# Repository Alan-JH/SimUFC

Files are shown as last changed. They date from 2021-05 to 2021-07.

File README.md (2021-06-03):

# SimUFC
UFC design for DCS, based on the F-18C Hornet

Display panels originally designed by [OpenHornet](https://github.com/jrsteensen/OpenHornet) and remixed to use .1" headers and multiplexed digits instead of multiplexed half digits.

Displays driven by Holtek HT1632Cs. Board is designed to take Cherry style key switches. I am using Kailh Box Jades, hence the SMD LEDs.

Main assembly is two large PCBs stacked, with the back PCB housing the LED drivers and microcontroller. It is designed to also take a shift register PCB of one of my older designs. It will be replaced later on.

Microcontroller is an STM32 Bluepill.

[][cc-by-nc-sa]

This work is licensed under a
[Creative Commons Attribution-NonCommercial-ShareAlike 4.0 International License][cc-by-nc-sa].

[][cc-by-nc-sa]

[cc-by-nc-sa]: http://creativecommons.org/licenses/by-nc-sa/4.0/
[cc-by-nc-sa-image]: https://licensebuttons.net/l/by-nc-sa/4.0/88x31.png
[cc-by-nc-sa-shield]: https://img.shields.io/badge/License-CC%20BY--NC--SA%204.0-lightgrey.svg

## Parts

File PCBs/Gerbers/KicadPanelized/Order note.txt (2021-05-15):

Please see Eco1_User and Cmts_User layers for internal cut instructions. The panel should include three modules, separated by mouse bite tabs.

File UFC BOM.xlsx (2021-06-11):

Category | Part | Qty | Price (Estimate) | Notes | Link
Switch | Kailh Box Jade keyswitch | 24 | $40 for 65 | clicc clacc | https://www.amazon.com/gp/product/B0841HQFCL/
Microcontroller | STM32F103C8T6 Bluepill | 1 | $14, with ST-Link programmer | cheaper on aliexpress etc. | https://www.ebay.com/itm/292286013429
LED Multiplexer | HT1632C-52LQFP | 2 | $6 for 5, from china | QFP52 part, buy from ebay/aliexpress. Adafruit uses HT16K33 for their 14 segs, seems to only be able to drive 8 at once. | https://www.ebay.com/itm/181847042276
 |  |  |  | HT1632C is EOL according to Holtek, but HT1632D, its replacement, is non stocked everywhere.
Resistor | 560R 1/4W 1206 | 34 | $14 for two assortments | 1206 SMD, Used for the multiplexer outputs to LEDs, should limit current to around 2mA | Assortment on amazon (buy two): https://www.amazon.com/gp/product/B08RYMYWG9
 | 300R 1/4W 1206 | 2 |  | 1206 SMD, Used for LED backlighting
 | 100R 1/4W 1206 | 22 |  | 1206 SMD, Used for LED backlighting (two LEDs in series, parallel with everything else. See schematic)
Diode | 1N4148 Diode | 17 | $5 for 125 |  | https://www.amazon.com/gp/product/B07Q4F3Y5W/
LED | Kingbright APT2012MGC | 24 | $11 | 0805 LED, used for backlighting keypads. Any ~2V, 20-30mA LED should work with this design. Recommend something decently bright | https://www.mouser.com/ProductDetail/kingbright/apt2012mgc/
Capacitor | 0603 .1uF X7R cap | 1 | $7 for a 100 pc reel | Decoupling capacitors | https://www.ebay.com/itm/202703146857
Displays | Modified Openhornet displays (OPT + Scratchpad + COM) | * | ~$40 for 5 panels | order from JLCPCB with SMT assembly | See gerber files on repo
 | ^Includes 177 0402 LEDs to be assembled
PCBs | Main PCB | 1 | ~$10 for 5 | order from JLCPCB, no SMT assembly. Solder yourself, or pay extra for SMT
 | Back side PCB | 1 | ~$10 for 5 | order from JLCPCB, no SMT assembly. Solder yourself, or pay extra for SMT
 | Lower Bar PCB | 1 | ~$6 for 5 | order from JLCPCB, no SMT assembly. Solder yourself, or pay extra for SMT
MOSFET | IPP120P04P4L03AKSA2 | 1 | $3 | Or other P channel mosfet of your choosing; requires low-ish RDSon, Id > 240mA at Vgs -5V, and Vgs threshold above 1.5V, give or take. | https://www.mouser.com/ProductDetail/726-IPP120P04P4L03A2
 |  |  |  | OR just redesign for analog control of backlight, with potentiometer of your choosing.
Connectors | Ribbon cable with Dupont connectors | 4 | ~$10, probably | Can be crimped yourself, but takes hours. Need two each of 8 wire, and 9 wire. Used for connecting comm displays
 | Female and male pin headers | * | $10 | Need lots of them. 40 pin, 30 pcs assortment is plenty. | https://www.amazon.com/gp/product/B074HVBTZ4/

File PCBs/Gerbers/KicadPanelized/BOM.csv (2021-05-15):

Comment | Designator | Footprint | LCSC Part Number
Green LED, 20mA | D1-177 | 0402 | C130722

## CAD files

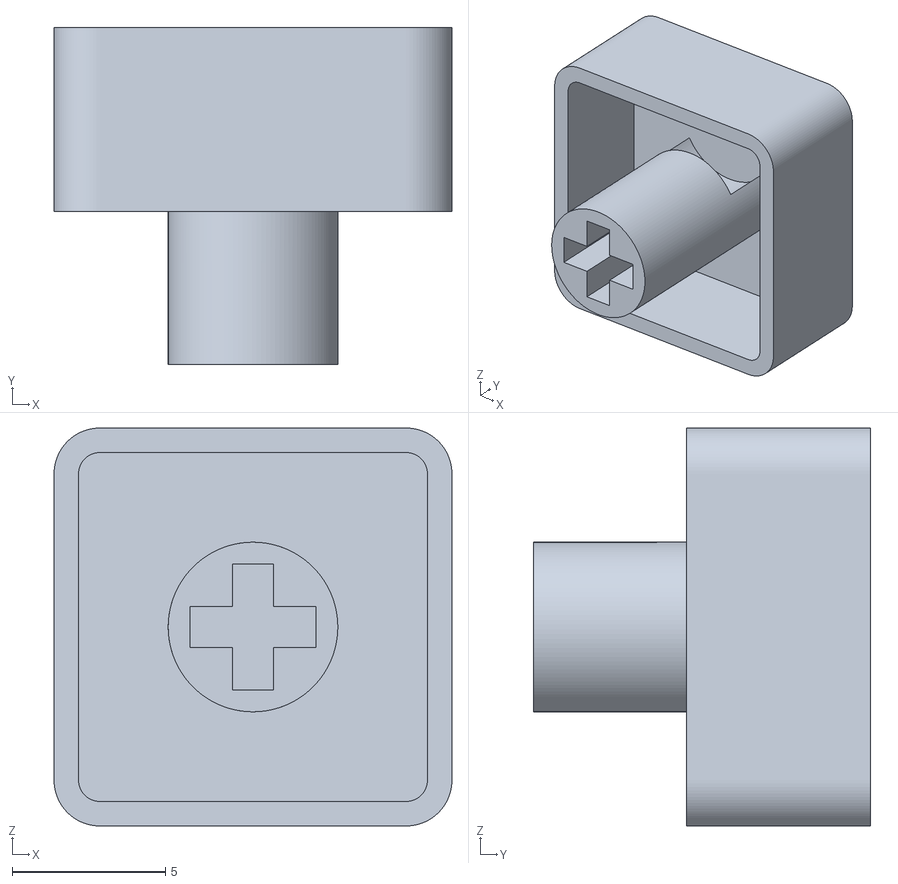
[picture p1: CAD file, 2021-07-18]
MCAD/STL Export/KeyENT.stl
13.0 x 11.0 x 13.0

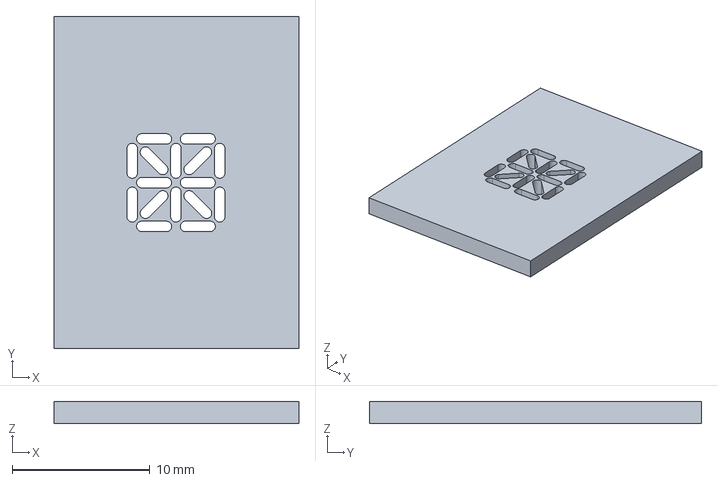
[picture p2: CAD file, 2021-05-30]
PCBs/Display layers updated/ufc_v4_comm_layer3.step
17.8 x 24.1 x 1.60 mm

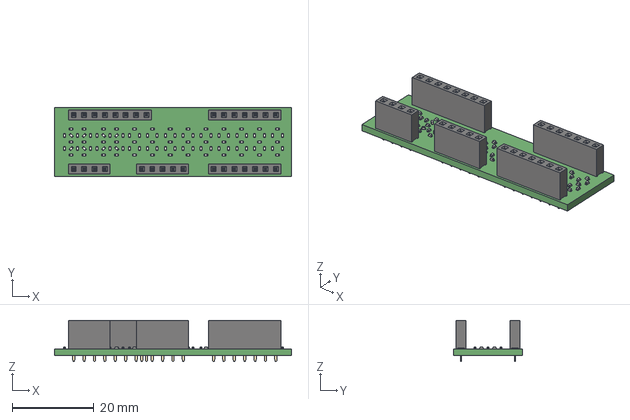
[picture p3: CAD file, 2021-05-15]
PCBs/ufc_v4_scratchpad.step
57.9 x 16.8 x 10.1 mm

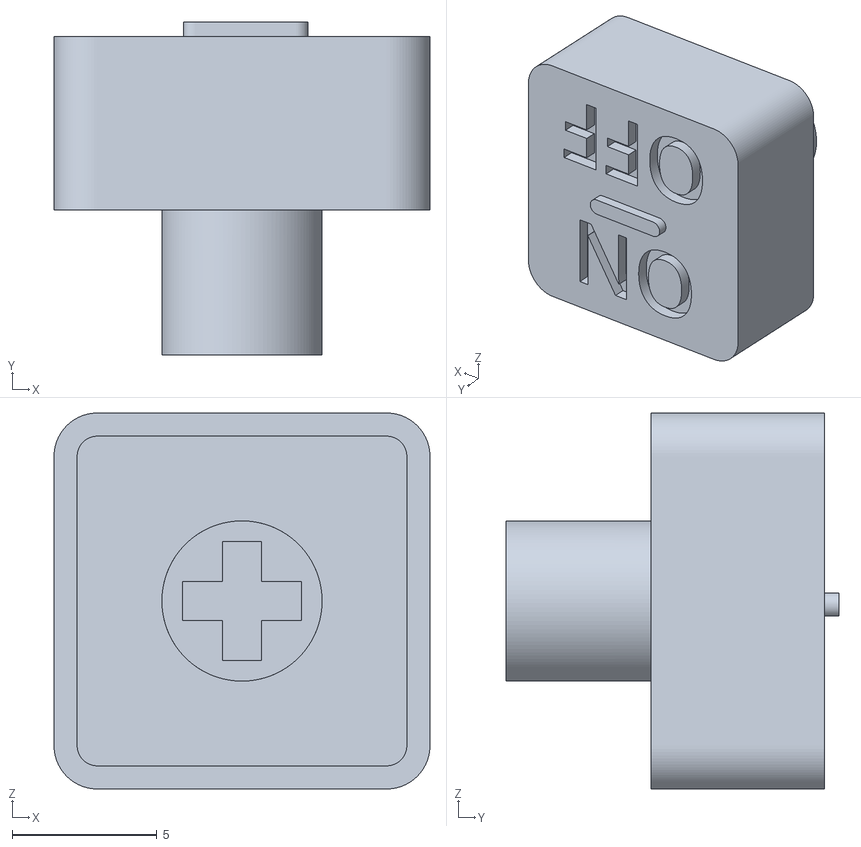
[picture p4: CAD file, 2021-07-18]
MCAD/STL Export/KeyONOFF.stl
13.0 x 11.5 x 13.0

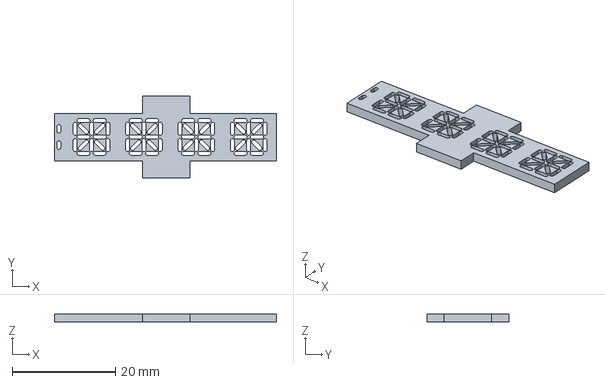
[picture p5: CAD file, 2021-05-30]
PCBs/Display layers updated/ufc_v4_opt_layer3.step
43.1 x 15.9 x 1.60 mm

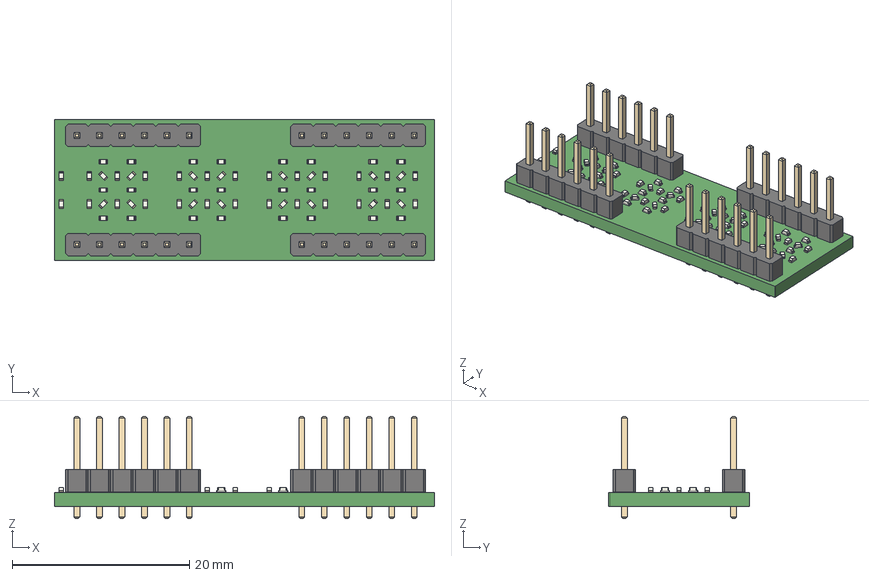
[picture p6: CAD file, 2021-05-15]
PCBs/ufc_v4_opt.step
42.9 x 15.9 x 11.5 mm

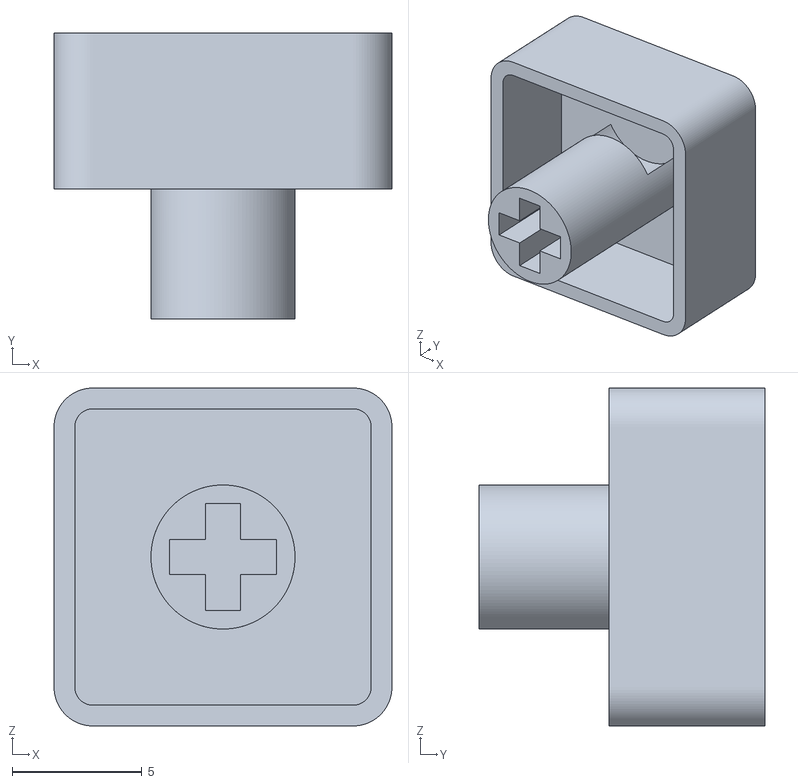
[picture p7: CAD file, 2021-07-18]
MCAD/STL Export/Key7.stl
13.0 x 11.0 x 13.0

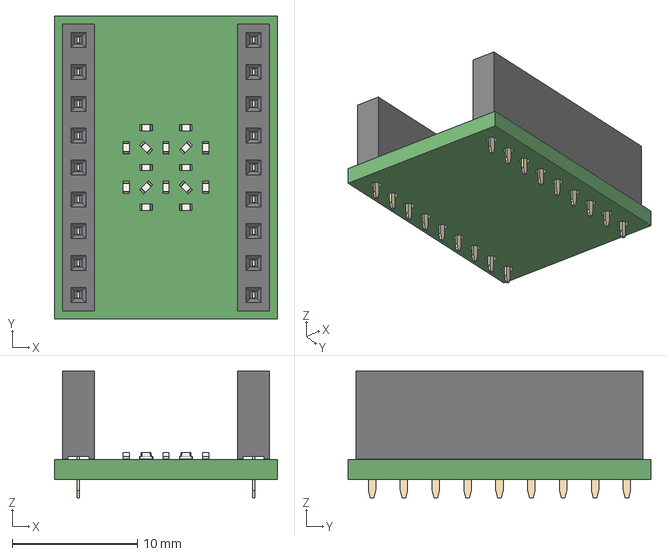
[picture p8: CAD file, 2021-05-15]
PCBs/ufc_v4_comm.step
17.8 x 24.1 x 10.1 mm

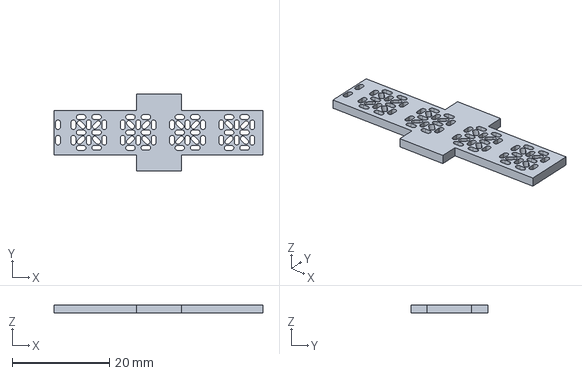
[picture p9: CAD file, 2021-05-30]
PCBs/Display layers updated/ufc_v4_opt_layer2.step
43.1 x 15.9 x 1.60 mm

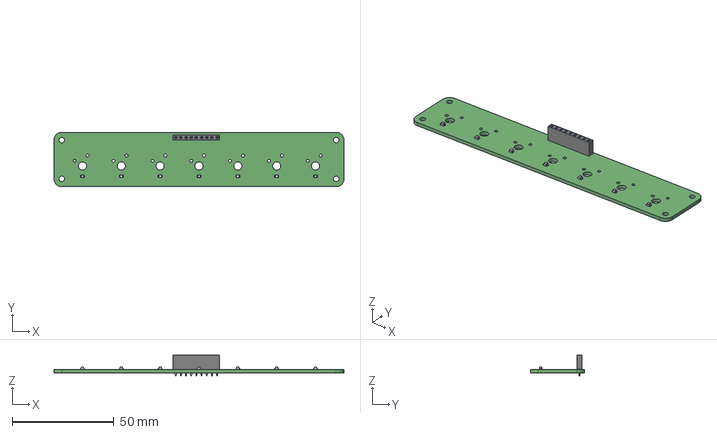
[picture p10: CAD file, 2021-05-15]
PCBs/LowerBar.step
142.2 x 26.7 x 10.1 mm

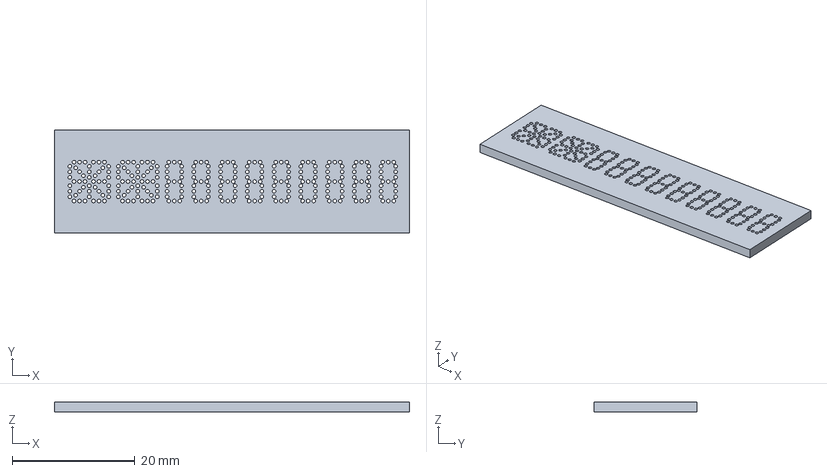
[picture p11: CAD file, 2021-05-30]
PCBs/Display layers updated/ufc_v4_scratchpad_layer4.step
58.0 x 16.8 x 1.60 mm

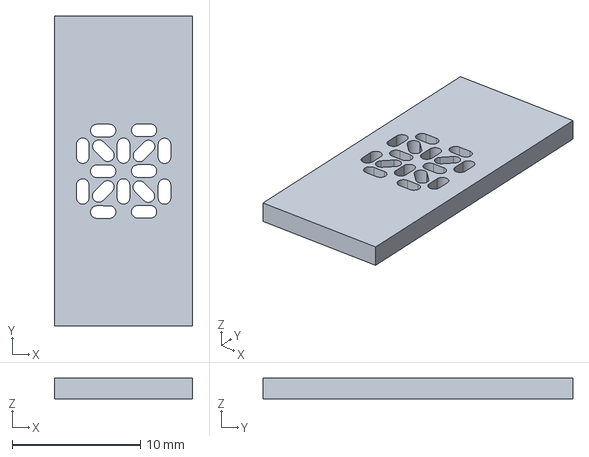
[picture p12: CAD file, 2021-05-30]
PCBs/Display layers updated/ufc_v4_comm_layer2.step
10.8 x 24.1 x 1.60 mm

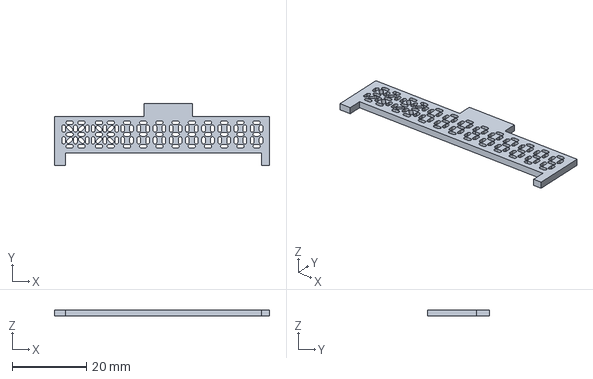
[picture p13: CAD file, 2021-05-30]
PCBs/Display layers updated/ufc_v4_scratchpad_layer2.step
58.0 x 16.8 x 1.60 mm

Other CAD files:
PCBs/Display layers updated/ufc_v4_comm_layer4.step
MCAD/STL Export/KeyIFF.stl
MCAD/STL Export/Key1.stl
MCAD/STL Export/Key6.stl
MCAD/STL Export/Key4.stl
MCAD/STL Export/Back.stl
MCAD/STL Export/COMM retainer.stl
MCAD/STL Export/COMM.stl
MCAD/STL Export/Face spacer.stl
MCAD/STL Export/Face.stl
MCAD/STL Export/Key0.stl
MCAD/STL Export/Key2.stl
MCAD/STL Export/Key3.stl
MCAD/STL Export/Key5.stl
MCAD/STL Export/Key8.stl
MCAD/STL Export/Key9.stl
MCAD/STL Export/KeyAP.stl
MCAD/STL Export/KeyBCN.stl
MCAD/STL Export/KeyCLR.stl
MCAD/STL Export/KeyDL.stl
MCAD/STL Export/KeyILS.stl
MCAD/STL Export/KeyRound.stl
MCAD/STL Export/KeyTCN.stl
MCAD/STL Export/Keypadplate.stl
MCAD/STL Export/L side.stl
MCAD/STL Export/Lower bar spacer.stl
MCAD/STL Export/Lower bar switch plate.stl
MCAD/STL Export/OPT retainer.stl
MCAD/STL Export/PCB spacer.stl
MCAD/STL Export/R side.stl
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

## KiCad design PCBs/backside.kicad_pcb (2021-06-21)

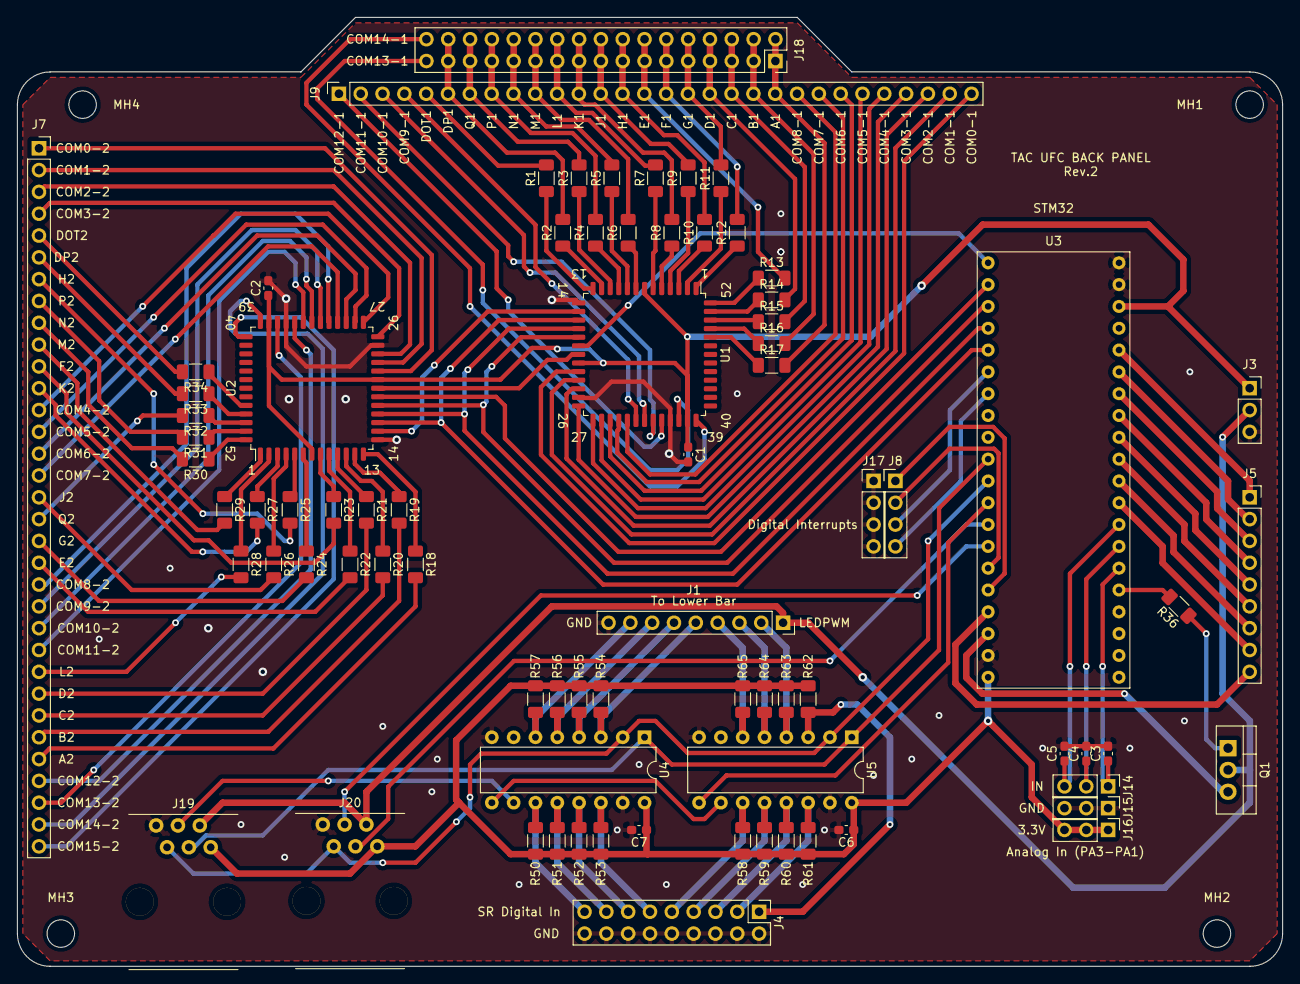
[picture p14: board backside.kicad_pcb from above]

Board: 2 copper layers, 147.3 x 110.5 mm, 82 parts (0 on the bottom side), 151 nets.

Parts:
C1, C2, C3, C4, C5, C6, C7: .1uF; C_0603_1608Metric_Pad1.08x0.95mm_HandSolder
J1: 9Pin; PinSocket_1x09_P2.54mm_Vertical
J3: Power; PinSocket_1x03_P2.54mm_Vertical
J4: Conn_02x09_Odd_Even; PinHeader_2x09_P2.54mm_Vertical
J5: Matrix; PinSocket_1x09_P2.54mm_Vertical
J7: Driver output 2; PinSocket_1x33_P2.54mm_Vertical
J8, J17: Conn_01x04_Male; PinHeader_1x04_P2.54mm_Vertical
J9: Conn_01x30_Male; PinSocket_1x30_P2.54mm_Vertical
J14, J15, J16: Conn_01x03_Male; PinHeader_1x03_P2.54mm_Vertical
J18: Conn_02x17_Odd_Even; PinSocket_2x17_P2.54mm_Vertical
J19, J20: RJ12; SS-6466-NF
MH1, MH2, MH3, MH4: MountingHole_3.2mm_M3
Q1: IPP120P04P4L03; TO-220-3_Vertical
R1, R2, R3, R4, R5, R6, R7, R8, R9, R10, R11, R12, R13, R14, R15, R16, R17, R18, R19, R20, R21, R22, R23, R24, R25, R26, R27, R28, R29, R30, R31, R32, R33, R34: 510R; R_1206_3216Metric_Pad1.30x1.75mm_HandSolder
R36: 100R; R_1206_3216Metric_Pad1.30x1.75mm_HandSolder
R50, R51, R52, R53, R54, R55, R56, R57, R58, R59, R60, R61, R62, R63, R64, R65: 10K; R_1206_3216Metric_Pad1.30x1.75mm_HandSolder
U1, U2: HT1632C-52LQFP; LQFP-52_14x14mm_P1mm
U3: STM32F103C8T6; Bluepill
U4, U5: 74HC165; DIP-16_W7.62mm

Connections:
/3.3V: C1.1, C2.1, C6.1, C7.1, J3.1, J16.1, J16.2, J16.3, J19.6, J20.6, R50.2, R51.2, R52.2, R53.2, R54.2, R55.2, R56.2, R57.2, R58.2, R59.2, R60.2, R61.2, R62.2, R63.2, R64.2, R65.2, U1.7, U1.21, U1.38, U2.7, U2.21, U2.38, U3.47, U3.52, U4.16, U5.16
/5V: Q1.3, U3.50
/A1: J9.21, J18.1, J18.2, R17.2
/A2: J7.29, R18.2
/Analog1: C3.1, J14.1, U3.11
/Analog2: C4.1, J14.2, U3.12
/Analog3: C5.1, J14.3, U3.13
/B1: J9.20, J18.3, J18.4, R16.2
/B2: J7.28, R19.2
/C1: J9.19, J18.5, J18.6, R15.2
/C2: J7.27, R20.2
/COL1: J5.4, U3.18
/COL2: J5.3, U3.19
/COL3: J5.2, U3.21
/COL4: J5.1, U3.22
/COM0-1: J9.30, U1.22
/COM0-2: J7.1, U2.22
/COM1-1: J9.29, U1.23
/COM1-2: J7.2, U2.23
/COM2-1: J9.28, U1.24
/COM2-2: J7.3, U2.24
/COM3-1: J9.27, U1.26
/COM3-2: J7.4, U2.26
/COM4-1: J9.26, U1.27
/COM4-2: J7.13, U2.27
/COM5-1: J9.25, U1.28
/COM5-2: J7.14, U2.28
/COM6-1: J9.24, U1.29
/COM6-2: J7.15, U2.29
/COM7-1: J9.23, U1.30
/COM7-2: J7.16, U2.30
/COM8-1: J9.22, U1.31
/COM8-2: J7.21, U2.31
/COM9-1: J9.4, U1.32
/COM9-2: J7.22, U2.32
/COM10-1: J9.3, U1.33
/COM10-2: J7.23, U2.33
/COM11-1: J9.2, U1.34
/COM11-2: J7.24, U2.34
/COM12-1: J9.1, U1.35
/COM12-2: J7.30, U2.35
/COM13-1: J18.33, U1.37
/COM13-2: J7.31, U2.37
/COM14-1: J18.34, U1.39
/COM14-2: J7.32, U2.39
/COM15-2: J7.33, U2.40
/CS1: U1.19, U3.25
/CS2: U2.19, U3.26
/D1: J9.18, J18.7, J18.8, R14.2
/D2: J7.26, R21.2
/DATA: U1.16, U2.16, U3.29
/DIN1: J4.1, R62.1, U5.3
/DIN2: J4.3, R61.1, U5.14
/DIN3: J4.5, R60.1, U5.13
/DIN4: J4.7, R59.1, U5.12
/DIN5: J4.9, R58.1, U5.11
/DIN6: J4.11, R53.1, U4.14
/DIN7: J4.13, R52.1, U4.13
/DIN8: J4.15, R51.1, U4.12
/DIN9: J4.17, R50.1, U4.11
/DOT1: J9.5, R1.2
/DOT2: J7.5, R34.2
/DP1: J9.6, J18.31, J18.32, R2.2
/DP2: J7.6, R33.2
/DSIN: J19.3, U4.10
/DigInt1: J8.1, U3.45
/DigInt2: J8.2, U3.43
/DigInt3: J8.3, U3.30
/DigInt4: J8.4, U3.31
/E1: J9.15, J18.13, J18.14, R13.2
/E2: J7.20, R22.2
/F1: J9.16, J18.11, J18.12, R12.2
/F2: J7.11, R23.2
/G1: J9.17, J18.9, J18.10, R11.2
/G2: J7.19, R24.2
/GND: C1.2, C2.2, C3.2, C4.2, C5.2, C6.2, C7.2, J1.9, J3.3, J4.2, J4.4, J4.6, J4.8, J4.10, J4.12, J4.14, J4.16, J4.18, J15.1, J15.2, J15.3, J17.1, J17.2, J17.3, J17.4, J19.1, J20.1, U1.14, U1.25, U1.36, U2.14, U2.25, U2.36, U3.48, U3.49, U3.51, U4.8, U4.15, U5.8, U5.15
/H1: J9.14, J18.15, J18.16, R10.2
/H2: J7.7, R25.2
/J1: J9.13, J18.17, J18.18, R9.2
/J2: J7.17, R26.2
/K1: J9.12, J18.19, J18.20, R8.2
/K2: J7.12, R27.2
/L1: J9.11, J18.21, J18.22, R7.2
/L2: J7.25, R28.2
/LEDPWM: J1.1, J3.2, J19.5, J20.5, Q1.2
/M1: J9.10, J18.23, J18.24, R6.2
/M2: J7.10, R29.2
/N1: J9.9, J18.25, J18.26, R5.2
/N2: J7.9, R30.2
/OSC: U1.15, U2.15
/P1: J9.8, J18.27, J18.28, R4.2
/P2: J7.8, R31.2
/Q1: J9.7, J18.29, J18.30, R3.2
/Q2: J7.18, R32.2
/RD: U1.18, U2.18, U3.27
/ROW0: J5.5, U3.17
/ROW1: J5.6, U3.16
/ROW2: J5.7, U3.15
/ROW3: J5.8, U3.14
/ROW4: J5.9, U3.46
/SRCLK: J19.2, J20.2, U3.39, U4.2, U5.2
/SRCS: J19.4, U3.38, U4.1, U5.1
/SRCS2: J20.4, U3.41
/SRMISO: U3.40, U5.9
/SRMISO2: J20.3, U3.42
/SW18: J1.8, R57.1, U4.6
/SW19: J1.7, R56.1, U4.5
/SW20: J1.6, R55.1, U4.4
/SW21: J1.5, R54.1, U4.3
/SW22: J1.4, R65.1, U5.6
/SW23: J1.3, R64.1, U5.5
/SW24: J1.2, R63.1, U5.4
/SYNC: U1.20, U2.20
/WR: U1.17, U2.17, U3.28
unnamed: Q1.1, R36.1
unnamed: R1.1, U1.13
unnamed: R2.1, U1.12
unnamed: R3.1, U1.11
unnamed: R4.1, U1.10
unnamed: R5.1, U1.9
unnamed: R6.1, U1.8
unnamed: R7.1, U1.6
unnamed: R8.1, U1.5
unnamed: R9.1, U1.4
unnamed: R10.1, U1.3
unnamed: R11.1, U1.2
unnamed: R12.1, U1.1
unnamed: R13.1, U1.52
unnamed: R14.1, U1.51
unnamed: R15.1, U1.50
unnamed: R16.1, U1.49
unnamed: R17.1, U1.48
unnamed: R18.1, U2.13
unnamed: R19.1, U2.12
unnamed: R20.1, U2.11
unnamed: R21.1, U2.10
unnamed: R22.1, U2.9
unnamed: R23.1, U2.8
unnamed: R24.1, U2.6
unnamed: R25.1, U2.5
unnamed: R26.1, U2.4
unnamed: R27.1, U2.3
unnamed: R28.1, U2.2
unnamed: R29.1, U2.1
unnamed: R30.1, U2.52
unnamed: R31.1, U2.51
unnamed: R32.1, U2.50
unnamed: R33.1, U2.49
unnamed: R34.1, U2.48
unnamed: R36.2, U3.10
unnamed: U4.9, U5.10

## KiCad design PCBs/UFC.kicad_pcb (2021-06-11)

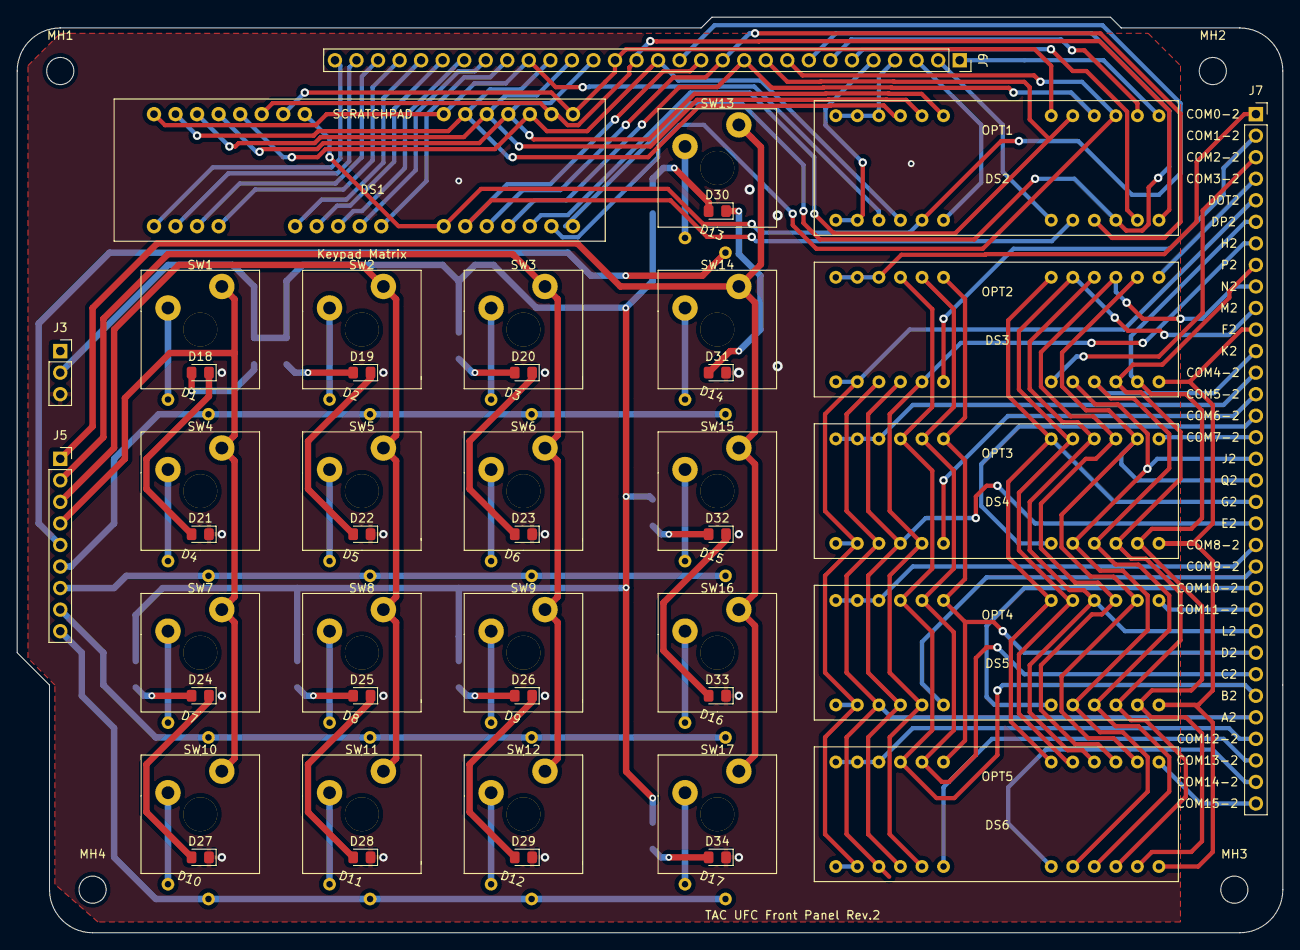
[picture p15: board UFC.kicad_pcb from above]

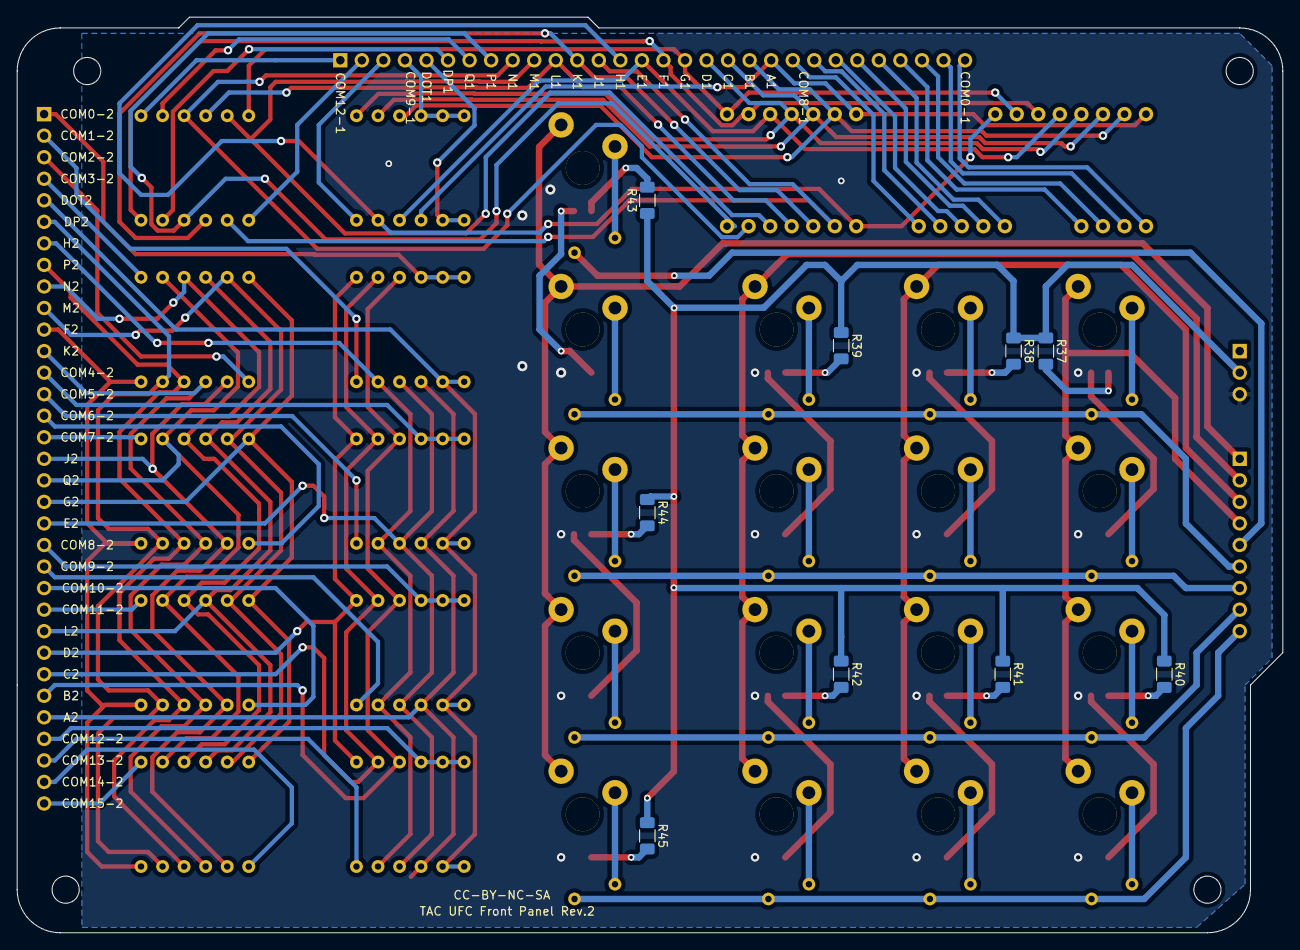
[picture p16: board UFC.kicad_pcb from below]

Board: 2 copper layers, 149.2 x 108.0 mm, 74 parts (9 on the bottom side), 108 nets.

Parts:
D1, D2, D3, D4, D5, D6, D7, D8, D9, D10, D11, D12, D13, D14, D15, D16, D17: D; 1N4148
D18, D19, D20, D21, D22, D23, D24, D25, D26, D27, D28, D29, D30, D31, D32, D33, D34: LED; LED_0805_2012Metric_Pad1.15x1.40mm_HandSolder
DS1: Scratchpad
DS2, DS3, DS4, DS5, DS6: CustomOptPanel; OPTDisplay
J3: Power; PinSocket_1x03_P2.54mm_Vertical
J5: Matrix; PinSocket_1x09_P2.54mm_Vertical
J7: Driver output 2; PinSocket_1x33_P2.54mm_Vertical
J9: Conn_01x30_Male; PinSocket_1x30_P2.54mm_Vertical
MH1, MH2, MH3, MH4: MountingHole_3.2mm_M3
R37, R38, R39, R40, R41, R42, R43, R44: 100R; R_1206_3216Metric_Pad1.30x1.75mm_HandSolder
R45: 300R; R_1206_3216Metric_Pad1.30x1.75mm_HandSolder
SW1, SW2, SW3, SW4, SW5, SW6, SW7, SW8, SW9, SW10, SW11, SW12, SW13, SW14, SW15, SW16, SW17: KeySW; KailhSW

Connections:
/A1: DS1.1, DS1.9, DS2.15, J9.21
/A2: DS3.15, DS4.15, DS5.15, DS6.15, J7.29
/B1: DS1.2, DS1.10, DS2.4, J9.20
/B2: DS3.4, DS4.4, DS5.4, DS6.4, J7.28
/C1: DS1.3, DS1.11, DS2.5, J9.19
/C2: DS3.5, DS4.5, DS5.5, DS6.5, J7.27
/COL1: J5.4, SW1.2, SW4.2, SW7.2, SW10.2
/COL2: J5.3, SW2.2, SW5.2, SW8.2, SW11.2
/COL3: J5.2, SW3.2, SW6.2, SW9.2, SW12.2
/COL4: J5.1, SW13.2, SW14.2, SW15.2, SW16.2, SW17.2
/COM0-1: DS1.16, J9.30
/COM0-2: DS3.1, DS3.2, DS3.3, J7.1
/COM1-1: DS1.17, J9.29
/COM1-2: DS3.18, J7.2
/COM2-1: DS1.18, J9.28
/COM2-2: DS3.19, J7.3
/COM3-1: DS1.19, J9.27
/COM3-2: DS3.12, J7.4
/COM4-1: DS1.20, J9.26
/COM4-2: DS4.1, DS4.2, DS4.3, J7.13
/COM5-1: DS1.21, J9.25
/COM5-2: DS4.18, J7.14
/COM6-1: DS1.22, J9.24
/COM6-2: DS4.19, J7.15
/COM7-1: DS1.23, J9.23
/COM7-2: DS4.12, J7.16
/COM8-1: DS1.24, J9.22
/COM8-2: DS5.1, DS5.2, DS5.3, J7.21
/COM9-1: DS2.1, DS2.2, DS2.3, J9.4
/COM9-2: DS5.18, J7.22
/COM10-1: DS2.18, J9.3
/COM10-2: DS5.19, J7.23
/COM11-1: DS2.19, J9.2
/COM11-2: DS5.12, J7.24
/COM12-1: DS2.12, J9.1
/COM12-2: DS6.1, DS6.2, DS6.3, J7.30
/COM13-2: DS6.18, J7.31
/COM14-2: DS6.19, J7.32
/COM15-2: DS6.12, J7.33
/D1: DS1.4, DS1.12, DS2.6, J9.18
/D2: DS3.6, DS4.6, DS5.6, DS6.6, J7.26
/DOT1: DS2.13, DS2.14, J9.5
/DOT2: DS3.13, DS3.14, DS4.13, DS4.14, DS5.13, DS5.14, DS6.13, DS6.14, J7.5
/DP1: DS2.23, J9.6
/DP2: DS3.23, DS4.23, DS5.23, DS6.23, J7.6
/E1: DS1.5, DS1.13, DS2.16, J9.15
/E2: DS3.16, DS4.16, DS5.16, DS6.16, J7.20
/F1: DS1.6, DS1.14, DS2.24, J9.16
/F2: DS3.24, DS4.24, DS5.24, DS6.24, J7.11
/G1: DS1.7, DS1.15, DS2.7, J9.17
/G2: DS3.7, DS4.7, DS5.7, DS6.7, J7.19
/GND: D21.1, D22.1, D23.1, D27.1, D28.1, D29.1, D31.1, D33.1, D34.1, J3.3
/H1: DS1.8, DS1.25, DS2.17, J9.14
/H2: DS3.17, DS4.17, DS5.17, DS6.17, J7.7
/J1: DS1.26, DS2.20, J9.13
/J2: DS3.20, DS4.20, DS5.20, DS6.20, J7.17
/K1: DS1.27, DS2.21, J9.12
/K2: DS3.21, DS4.21, DS5.21, DS6.21, J7.12
/L1: DS1.28, DS2.9, J9.11
/L2: DS3.9, DS4.9, DS5.9, DS6.9, J7.25
/LEDPWM: J3.2, R37.1, R38.1, R39.1, R40.1, R41.1, R42.1, R43.1, R44.1, R45.1
/M1: DS1.29, DS2.8, J9.10
/M2: DS3.8, DS4.8, DS5.8, DS6.8, J7.10
/N1: DS1.30, DS2.10, J9.9
/N2: DS3.10, DS4.10, DS5.10, DS6.10, J7.9
/P1: DS1.31, DS2.22, J9.8
/P2: DS3.22, DS4.22, DS5.22, DS6.22, J7.8
/Q1: DS2.11, J9.7
/Q2: DS3.11, DS4.11, DS5.11, DS6.11, J7.18
/ROW0: D13.1, J5.5
/ROW1: D1.1, D2.1, D3.1, D14.1, J5.6
/ROW2: D4.1, D5.1, D6.1, D15.1, J5.7
/ROW3: D7.1, D8.1, D9.1, D16.1, J5.8
/ROW4: D10.1, D11.1, D12.1, D17.1, J5.9
unnamed: D1.2, SW1.1
unnamed: D2.2, SW2.1
unnamed: D3.2, SW3.1
unnamed: D4.2, SW4.1
unnamed: D5.2, SW5.1
unnamed: D6.2, SW6.1
unnamed: D7.2, SW7.1
unnamed: D8.2, SW8.1
unnamed: D9.2, SW9.1
unnamed: D10.2, SW10.1
unnamed: D11.2, SW11.1
unnamed: D12.2, SW12.1
unnamed: D13.2, SW13.1
unnamed: D14.2, SW14.1
unnamed: D15.2, SW15.1
unnamed: D16.2, SW16.1
unnamed: D17.2, SW17.1
unnamed: D18.1, D21.2
unnamed: D18.2, R37.2
unnamed: D19.1, D22.2
unnamed: D19.2, R38.2
unnamed: D20.1, D23.2
unnamed: D20.2, R39.2
unnamed: D24.1, D27.2
unnamed: D24.2, R40.2
unnamed: D25.1, D28.2
unnamed: D25.2, R41.2
unnamed: D26.1, D29.2
unnamed: D26.2, R42.2
unnamed: D30.1, D31.2
unnamed: D30.2, R43.2
unnamed: D32.1, D33.2
unnamed: D32.2, R44.2
unnamed: D34.2, R45.2

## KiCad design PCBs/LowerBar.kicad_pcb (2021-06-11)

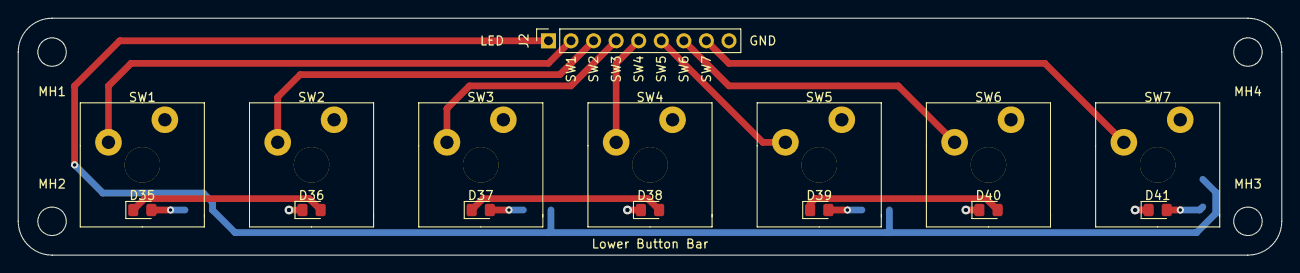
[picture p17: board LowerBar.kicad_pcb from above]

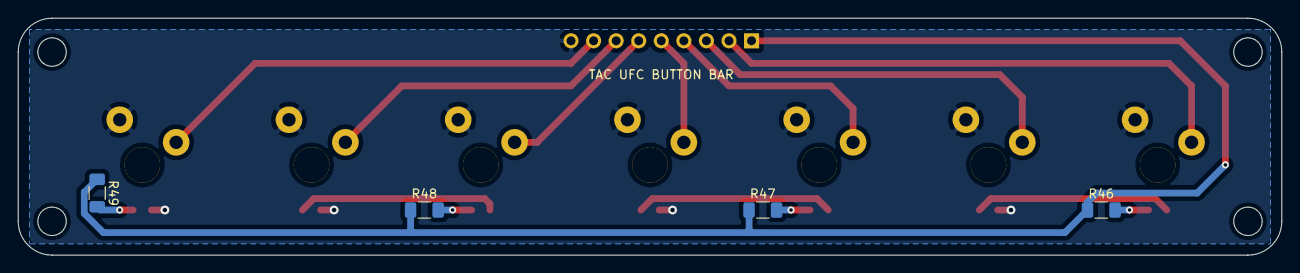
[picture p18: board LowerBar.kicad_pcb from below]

Board: 2 copper layers, 142.2 x 26.7 mm, 23 parts (4 on the bottom side), 16 nets.

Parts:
D35, D36, D37, D38, D39, D40, D41: LED; LED_0805_2012Metric_Pad1.15x1.40mm_HandSolder
J2: 9pin; PinSocket_1x09_P2.54mm_Vertical
MH1, MH2, MH3, MH4: M3; MountingHole_3.2mm_M3
R46, R47, R48: 100R; R_1206_3216Metric_Pad1.30x1.75mm_HandSolder
R49: 300R; R_1206_3216Metric_Pad1.30x1.75mm_HandSolder
SW1, SW2, SW3, SW4, SW5, SW6, SW7: KeySW; KailhSW

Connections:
/GND: D36.1, D38.1, D40.1, D41.1, J2.9, SW1.2, SW2.2, SW3.2, SW4.2, SW5.2, SW6.2, SW7.2
/LED: J2.1, R46.1, R47.1, R48.1, R49.1
/SW18: J2.2, SW1.1
/SW19: J2.3, SW2.1
/SW20: J2.4, SW3.1
/SW21: J2.5, SW4.1
/SW22: J2.6, SW5.1
/SW23: J2.7, SW6.1
/SW24: J2.8, SW7.1
unnamed: D35.1, D36.2
unnamed: D35.2, R46.2
unnamed: D37.1, D38.2
unnamed: D37.2, R47.2
unnamed: D39.1, D40.2
unnamed: D39.2, R48.2
unnamed: D41.2, R49.2

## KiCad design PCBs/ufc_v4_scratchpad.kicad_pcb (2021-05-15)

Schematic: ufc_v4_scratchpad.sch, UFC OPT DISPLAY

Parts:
D1, D2, D3, D4, D5, D6, D7, D8, D9, D10, D11, D12, D13, D14, D15, D16, D17, D18, D19, D20, D21, D22, D23, D24, D25, D26, D27, D28, D29, D30, D31, D32, D33, D34, D35, D36, D37, D38, D39, D40, D41, D42, D43, D44, D45, D46, D47, D48, D49, D50, D51, D52, D53, D54, D55, D56, D57, D58, D59, D60, D61, D62, D63, D64, D65, D66, D67, D68, D69, D70, D71, D72, D73, D74, D75, D76, D77, D78, D79, D80, D81, D82, D83, D84, D85, D86, D87, D88, D89, D90, D91, D92, D93, D94, D95: LED; LED_0402_1005Metric; LCSC C130723
J1: Conn_01x08_Male; PinHeader_1x08_P2.54mm_Vertical
J2: Conn_01x04_Male; PinHeader_1x04_P2.54mm_Vertical
J3, J5: Conn_01x07_Male; PinHeader_1x07_P2.54mm_Vertical
J6: Conn_01x05_Male; PinHeader_1x05_P2.54mm_Vertical

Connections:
/DIG0: D1.1 (K), D2.1 (K), D3.1 (K), D4.1 (K), D5.1 (K), D6.1 (K), D7.1 (K), D8.1 (K), J2.1
/DIG0_2: D33.1 (K), D34.1 (K), D35.1 (K), D36.1 (K), D37.1 (K), D38.1 (K), D39.1 (K), D61.1 (K), D62.1 (K), D63.1 (K), D64.1 (K), D65.1 (K), D66.1 (K), D67.1 (K), J6.1
/DIG1: D9.1 (K), D10.1 (K), D11.1 (K), D12.1 (K), D13.1 (K), D14.1 (K), D15.1 (K), D16.1 (K), J2.2
/DIG1_2: D40.1 (K), D41.1 (K), D42.1 (K), D43.1 (K), D44.1 (K), D45.1 (K), D46.1 (K), D68.1 (K), D69.1 (K), D70.1 (K), D71.1 (K), D72.1 (K), D73.1 (K), D74.1 (K), J6.2
/DIG2: D17.1 (K), D18.1 (K), D19.1 (K), D20.1 (K), D21.1 (K), D22.1 (K), D23.1 (K), D24.1 (K), J2.3
/DIG2_2: D47.1 (K), D48.1 (K), D49.1 (K), D50.1 (K), D51.1 (K), D52.1 (K), D53.1 (K), D75.1 (K), D76.1 (K), D77.1 (K), D78.1 (K), D79.1 (K), D80.1 (K), D81.1 (K), J6.3
/DIG3: D25.1 (K), D26.1 (K), D27.1 (K), D28.1 (K), D29.1 (K), D30.1 (K), D31.1 (K), D32.1 (K), J2.4
/DIG3_2: D54.1 (K), D55.1 (K), D56.1 (K), D57.1 (K), D58.1 (K), D59.1 (K), D60.1 (K), D82.1 (K), D83.1 (K), D84.1 (K), D85.1 (K), D86.1 (K), D87.1 (K), D88.1 (K), J6.4
/DIG4_2: D89.1 (K), D90.1 (K), D91.1 (K), D92.1 (K), D93.1 (K), D94.1 (K), D95.1 (K), J6.5
/SEGA: D1.2 (A), D9.2 (A), D17.2 (A), D25.2 (A), J1.1
/SEGA2: D33.2 (A), D40.2 (A), D47.2 (A), D54.2 (A), J3.1
/SEGB: D2.2 (A), D10.2 (A), D18.2 (A), D26.2 (A), J1.2
/SEGB2: D34.2 (A), D41.2 (A), D48.2 (A), D55.2 (A), J3.2
/SEGC: D3.2 (A), D11.2 (A), D19.2 (A), D27.2 (A), J1.3
/SEGC2: D35.2 (A), D42.2 (A), D49.2 (A), D56.2 (A), J3.3
/SEGD: D4.2 (A), D12.2 (A), D20.2 (A), D28.2 (A), J1.4
/SEGD2: D36.2 (A), D43.2 (A), D50.2 (A), D57.2 (A), J3.4
/SEGE: D5.2 (A), D13.2 (A), D21.2 (A), D29.2 (A), J1.5
/SEGE2: D37.2 (A), D44.2 (A), D51.2 (A), D58.2 (A), J3.5
/SEGF: D6.2 (A), D14.2 (A), D22.2 (A), D30.2 (A), J1.6
/SEGF2: D38.2 (A), D45.2 (A), D52.2 (A), D59.2 (A), J3.6
/SEGG: D7.2 (A), D15.2 (A), D23.2 (A), D31.2 (A), J1.7
/SEGG2: D39.2 (A), D46.2 (A), D53.2 (A), D60.2 (A), J3.7
/SEGH: D8.2 (A), D16.2 (A), D24.2 (A), D32.2 (A), J1.8
/SEGH2: D61.2 (A), D68.2 (A), D75.2 (A), D82.2 (A), D89.2 (A), J5.1
/SEGJ2: D62.2 (A), D69.2 (A), D76.2 (A), D83.2 (A), D90.2 (A), J5.2
/SEGK2: D63.2 (A), D70.2 (A), D77.2 (A), D84.2 (A), D91.2 (A), J5.3
/SEGL2: D64.2 (A), D71.2 (A), D78.2 (A), D85.2 (A), D92.2 (A), J5.4
/SEGM2: D65.2 (A), D72.2 (A), D79.2 (A), D86.2 (A), D93.2 (A), J5.5
/SEGN2: D66.2 (A), D73.2 (A), D80.2 (A), D87.2 (A), D94.2 (A), J5.6
/SEGP2: D67.2 (A), D74.2 (A), D81.2 (A), D88.2 (A), D95.2 (A), J5.7

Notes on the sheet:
PCB Dims: 57x15mm 2x 16-deg, 9x 7-seg

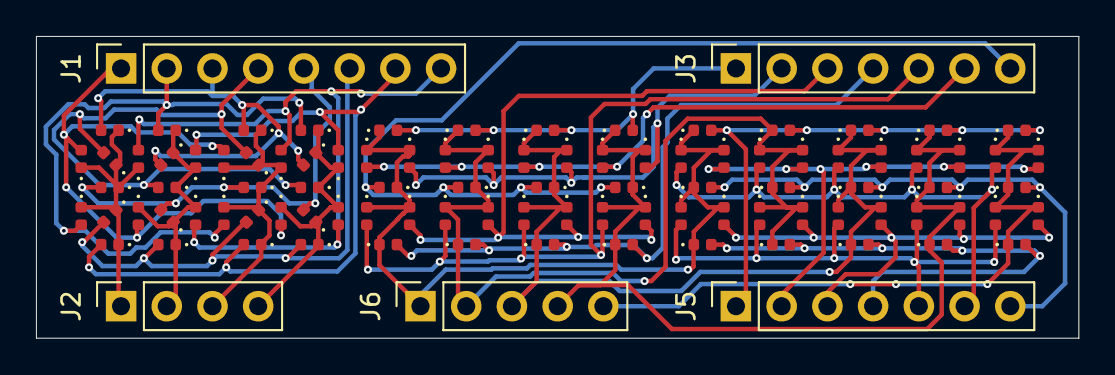
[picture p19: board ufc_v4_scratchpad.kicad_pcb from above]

Board: 2 copper layers, 57.9 x 16.8 mm, 100 parts (0 on the bottom side), 31 nets.

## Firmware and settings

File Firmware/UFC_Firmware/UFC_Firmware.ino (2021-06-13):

//UFC Firmware
//Alan H.
//6-12-21

#define DCSBIOS_FOR_STM32
#define DCSBIOS_DEFAULT_SERIAL


#include <SPI.h> //rogerclarkmelbourne STM32 SPI lib, comes with Arduino_STM32 core
#include <Wire.h>
#include <USBComposite.h> //Arduino_STM32 USB Composite library for HID reporting
#include "Adafruit_HT1632.h" //Adafruit HT1632C library, intended for their 24x16 display. https://github.com/adafruit/HT1632
#include "DcsBios.h" //DCS Bios arduino  library, 0.35 branch. https://github.com/talbotmcinnis/dcs-bios-arduino-library MUST MODIFY LIBRARY FILES BEFORE USING.
#include "SegmentMap.h" //Contains data about which digit and segment corresponds to which hardware x,y
#include "CharacterMap.h" //Contains data about which segments are to be lit for each character

#define HT_DATA PA8
#define HT_WR PB15
#define HT_CS1 PB12
#define HT_CS2 PB13
#define BACKLIGHT PA0 //Backlight PWM out
#define SRLATCH PA15
#define NUMSRS 3

#define NUMROWS 5
#define NUMCOLS 4
#define NUMMATRIX 17

uint64_t buttonState = 0;

int rows[NUMROWS] = {PB9, PB8, PB7, PB6, PB5}; //Row and Column pins
int cols[NUMCOLS] = {PB0, PB1, PB10, PB11};

int buttonIDs[NUMROWS][NUMCOLS] = { //Matrix button IDs
  {-1, -1, -1, 12},
  { 0,  1,  2, 13},
  { 3,  4,  5, 14},
  { 6,  7,  8, 15}, 
  { 9, 10, 11, 16}
};

int SRButtons[8*NUMSRS] = { //Shift register button IDs
  17, 18, 19, 20, 21, 22, 23, 24, 25, 26, 27, 28, 29, 30, 31, 32, 33, 34, 35, 36, 37, 38, 39, 40
};

bool prevCodes[NUMROWS][NUMCOLS]; //Previous matrix state

#define HID_SIGNED_JOYSTICK_REPORT_DESCRIPTOR(...) \
  0x05, 0x01,           /*  Usage Page (Generic Desktop) */ \
  0x09, 0x04,           /*  Usage (Joystick) */ \
  0xA1, 0x01,           /*  Collection (Application) */ \
  0x85, MACRO_GET_ARGUMENT_1_WITH_DEFAULT(HID_JOYSTICK_REPORT_ID, ## __VA_ARGS__),  /*    REPORT_ID */ \
  0x15, 0x00,           /*   Logical Minimum (0) */ \
  0x25, 0x01,           /*    Logical Maximum (1) */ \
  0x75, 0x01,           /*    Report Size (1) */ \
  0x95, 0x40,           /*    Report Count (64) */ \
  0x05, 0x09,           /*    Usage Page (Button) */ \
  0x19, 0x01,           /*    Usage Minimum (Button #1) */ \
  0x29, 0x40,           /*    Usage Maximum (Button #64) */ \
  0x81, 0x02,           /*    Input (variable,absolute) */ \
  0x15, 0x00,           /*    Logical Minimum (0) */ \
  0x25, 0x07,           /*    Logical Maximum (7) */ \
  0x35, 0x00,           /*    Physical Minimum (0) */ \
  0x46, 0x3B, 0x01,       /*    Physical Maximum (315) */ \
  0x75, 0x04,           /*    Report Size (4) */ \
  0x95, 0x01,           /*    Report Count (1) */ \
  0x65, 0x14,           /*    Unit (20) */ \
    0x05, 0x01,                     /*    Usage Page (Generic Desktop) */ \
  0x09, 0x39,           /*    Usage (Hat switch) */ \
  0x81, 0x42,           /*    Input (variable,absolute,null_state) */ \
    0x05, 0x01,                     /* Usage Page (Generic Desktop) */ \
  0x09, 0x01,           /* Usage (Pointer) */ \
    0xA1, 0x00,                     /* Collection () */ \
  0x16, 0x00, 0xFC,           /*    Logical Minimum (-1024) */ \
  0x26, 0xFF, 0x03,       /*    Logical Maximum (1023) */ \
  0x75, 0x0B,           /*    Report Size (11) */ \
  0x95, 0x04,           /*    Report Count (4) */ \
  0x09, 0x30,           /*    Usage (X) */ \
  0x09, 0x31,           /*    Usage (Y) */ \
  0x09, 0x33,           /*    Usage (Rx) */ \
  0x09, 0x34,           /*    Usage (Ry) */ \
  0x81, 0x02,           /*    Input (variable,absolute) */ \
    0xC0,                           /*  End Collection */ \
  0x15, 0x00,           /*  Logical Minimum (0) */ \
  0x26, 0xFF, 0x03,       /*  Logical Maximum (1023) */ \
  0x75, 0x0A,           /*  Report Size (10) */ \
  0x95, 0x02,           /*  Report Count (2) */ \
  0x09, 0x36,           /*  Usage (Slider) */ \
  0x09, 0x36,           /*  Usage (Slider) */ \
  0x81, 0x02,           /*  Input (variable,absolute) */ \
  0x75, 0x04,                    /*   REPORT_SIZE (4) */ \
  0x95, 0x01,                    /*   REPORT_COUNT (1) */ \
  0x81, 0x03,                    /*   OUTPUT (Cnst,Var,Abs) */ \  
  MACRO_ARGUMENT_2_TO_END(__VA_ARGS__)  \
  0xC0

typedef struct {
    uint8_t reportID;
    uint64_t buttons;
    unsigned hat:4;
    int x:11;
    int y:11;
    int rx:11;
    int ry:11;
    unsigned sliderLeft:10;
    unsigned sliderRight:10;
    unsigned unused:4;
} __packed SignedJoystickReport_t;

class HIDSignedJoystick : public HIDReporter {
public:
  SignedJoystickReport_t joyReport; 
  void begin(void) {};
  void end(void) {};
  HIDSignedJoystick(USBHID& HID, uint8_t reportID=HID_JOYSTICK_REPORT_ID) 
            : HIDReporter(HID, NULL, (uint8_t*)&joyReport, sizeof(joyReport), reportID) {
        joyReport.buttons = 0;
        joyReport.hat = 15;
        joyReport.x = 0;
        joyReport.y = 0;
        joyReport.rx = 0;
        joyReport.ry = 0;
        joyReport.sliderLeft = 0;
        joyReport.sliderRight = 0;
    }
};

USBHID HID;
USBCompositeSerial CompositeSerial;
HIDSignedJoystick joy(HID);

uint8 signedJoyReportDescriptor[] = {
  HID_SIGNED_JOYSTICK_REPORT_DESCRIPTOR()
};

  
Adafruit_HT1632LEDMatrix matrix = Adafruit_HT1632LEDMatrix(HT_DATA, HT_WR, HT_CS1, HT_CS2); //Adafruit HT1632 matrix

void setup() {

    // Remap SPI 1
  // Source: https://community.platformio.org/t/pio-arduino-stm32f103cbt6-remap/6786/5
  afio_cfg_debug_ports(AFIO_DEBUG_SW_ONLY); // PB3 free
  afio_remap(AFIO_REMAP_SPI1);

  gpio_set_mode (GPIOB, 3, GPIO_AF_OUTPUT_PP);
  gpio_set_mode (GPIOB, 4, GPIO_INPUT_FLOATING);
  gpio_set_mode (GPIOB, 5, GPIO_AF_OUTPUT_PP);
  
  // Setup SPI 1
  SPI.begin(); //Initialize the SPI_1 port.
  SPI.setBitOrder(MSBFIRST); // Set the SPI_1 bit order
  SPI.setDataMode(SPI_MODE0); //Set the  SPI_2 data mode 0
  SPI.setClockDivider(SPI_CLOCK_DIV16);      // Slow speed (72 / 16 = 4.5 MHz SPI_1 speed)
  pinMode(SRLATCH, OUTPUT); //initialize srlatch and set high
  digitalWrite(SRLATCH, HIGH);

  //Configure matrix pins
  for (int i = 0; i < NUMCOLS; i++){
    pinMode(cols[i], INPUT_PULLUP);
  }
  for (int i = 0; i < NUMROWS; i++){
    pinMode(rows[i], INPUT);
  }
  
  //HID stuff
  HID.begin(CompositeSerial, signedJoyReportDescriptor, sizeof(signedJoyReportDescriptor));
  HID.registerComponent();
  //USBComposite.begin();  
  while (!USBComposite);

  
  
  //Start matrix
  matrix.begin(ADA_HT1632_COMMON_16NMOS);
  matrix.fillScreen();
  delay(2000);
  matrix.clearScreen();
  matrix.setTextWrap(false);
  matrix.setRotation(0);

  pinMode(BACKLIGHT, OUTPUT);
  analogWrite(BACKLIGHT, 255);
}

void checkMatrix(){
  for (int row = 0; row < NUMROWS; row++){ //Iterate through each row, set pin to output, LOW
    pinMode(rows[row], OUTPUT);
    digitalWrite(rows[row], LOW);
    for (int col = 0; col < NUMCOLS; col++){ //Check which column pins are now LOW (on)
      if (buttonIDs[row][col] != -1){
        if (digitalRead(cols[col]) == LOW){ //ON
          if (!prevCodes[row][col]){
            buttonState = buttonState | (1 << buttonIDs[row][col]);
          }
          prevCodes[row][col] = true;
        }else{                              //OFF
          if (prevCodes[row][col]){ 
            buttonState = buttonState & (~ (1 << buttonIDs[row][col]));
          }
          prevCodes[row][col] = false;
        }
      }
    }
    pinMode(rows[row], INPUT);
  }
}

uint64_t SRDATA = 0;

void checkSRs(){ //Read from Shift Registers using SPI
  digitalWrite(SRLATCH, LOW); //Pulse load latch
  digitalWrite(SRLATCH, HIGH);
  SRDATA = SPI.transfer(0); //Read first bank
  for (int i = 1; i < NUMSRS; i++){ //For the rest of the banks, bitshift data left 8, then set bits to next bank
    SRDATA = SRDATA << 8;
    SRDATA = SRDATA | SPI.transfer(0);
  }
  SRDATA = ~ SRDATA; //Invert data, assumes shift registers are pulled up
  SRDATA = SRDATA & (uint32_t)(pow(2, NUMSRS*8) - 1);     //clear data after last shift register
  buttonState = buttonState & ((uint32_t)(pow(2, 17))-1); //clear shift registers in button data
  buttonState = buttonState | (SRDATA << NUMMATRIX); //Set new button data
}

int SearchIndex(String goal){
  int result = -1;
  for (int i = 0; i < lenChars; i++){
    if (characters[i].equals(goal)) result = i;
  }
  return result;
}

void DisplayChar(uint8_t segs[][2], uint8_t characterSegs[], int len){ //array of segment coordinates, array of segment light/dark, and length (7, or 16)
  for (int i = 0; i < len; i++){
    matrix.drawPixel(int(segs[i][0]), int(segs[i][1]), int(characterSegs[i]));
  }
}

//DCS-BIOS F-18 Functions:
void onUfcScratchpadString1DisplayChange(char* newValue) {
  String newString = String(newValue);
  newString.trim();
  if (newString.length() == 0){
    newString = " ";
  }
  int check = SearchIndex(newString);
  if (check == -1) return;
  DisplayChar(ScratchPad16[0], Map16[check], 16);
  matrix.writeScreen();
}
DcsBios::StringBuffer<2> ufcScratchpadString1DisplayBuffer(0x744e, onUfcScratchpadString1DisplayChange);
void onUfcScratchpadString2DisplayChange(char* newValue) {
  String newString = String(newValue);
  newString.trim();
  if (newString.length() == 0){
    newString = " ";
  }
  int check = SearchIndex(newString);
  if (check == -1) return;
  DisplayChar(ScratchPad16[1], Map16[check], 16);
  matrix.writeScreen();
}
DcsBios::StringBuffer<2> ufcScratchpadString2DisplayBuffer(0x7450, onUfcScratchpadString2DisplayChange);
void onUfcScratchpadNumberDisplayChange(char* newValue) {
  String newString = String(newValue);
  for (int i = 1; i < newString.length(); i++){
    int check = SearchIndex(newString.substring(i, i+1));
    if (check == -1) return;
    DisplayChar(ScratchPad7[i-1], Map7[check], 7);
  }
  matrix.writeScreen();
}
DcsBios::StringBuffer<8> ufcScratchpadNumberDisplayBuffer(0x7446, onUfcScratchpadNumberDisplayChange);

//OPT
void onUfcOptionDisplay1Change(char* newValue) {
  String newString = String(newValue);
  for (int i = 0; i < newString.length(); i++){
    int check = SearchIndex(newString.substring(i, i+1));
    if (check == -1) return;
    DisplayChar(OPT1Disp[i], Map16[check], 16);
  }
  matrix.writeScreen();
}
DcsBios::StringBuffer<4> ufcOptionDisplay1Buffer(0x7432, onUfcOptionDisplay1Change);
void onUfcOptionDisplay2Change(char* newValue) {
  String newString = String(newValue);
  for (int i = 0; i < newString.length(); i++){
    int check = SearchIndex(newString.substring(i, i+1));
    if (check == -1) return;
    DisplayChar(OPT2Disp[i], Map16[check], 16);
  }
  matrix.writeScreen();
}
DcsBios::StringBuffer<4> ufcOptionDisplay2Buffer(0x7436, onUfcOptionDisplay2Change);
void onUfcOptionDisplay3Change(char* newValue) {
  String newString = String(newValue);
  for (int i = 0; i < newString.length(); i++){
    int check = SearchIndex(newString.substring(i, i+1));
    if (check == -1) return;
    DisplayChar(OPT3Disp[i], Map16[check], 16);
  }
  matrix.writeScreen();
}
DcsBios::StringBuffer<4> ufcOptionDisplay3Buffer(0x743a, onUfcOptionDisplay3Change);
void onUfcOptionDisplay4Change(char* newValue) {
  String newString = String(newValue);
  for (int i = 0; i < newString.length(); i++){
    int check = SearchIndex(newString.substring(i, i+1));
    if (check == -1) return;
    DisplayChar(OPT4Disp[i], Map16[check], 16);
  }
  matrix.writeScreen();
}
DcsBios::StringBuffer<4> ufcOptionDisplay4Buffer(0x743e, onUfcOptionDisplay4Change);
void onUfcOptionDisplay5Change(char* newValue) {
  String newString = String(newValue);
  for (int i = 0; i < newString.length(); i++){
    int check = SearchIndex(newString.substring(i, i+1));
    if (check == -1) return;
    DisplayChar(OPT5Disp[i], Map16[check], 16);
  }
  matrix.writeScreen();
}
DcsBios::StringBuffer<4> ufcOptionDisplay5Buffer(0x7442, onUfcOptionDisplay5Change);

void onUfcOptionCueing1Change(char* newValue) {
  if (String(newValue).equals(" ")){
    matrix.clrPixel(OPT1Dot[0][0][0], OPT1Dot[0][0][1]);
  }else{
    matrix.setPixel(OPT1Dot[0][0][0], OPT1Dot[0][0][1]);
  }
  matrix.writeScreen();
}
DcsBios::StringBuffer<1> ufcOptionCueing1Buffer(0x7428, onUfcOptionCueing1Change);

void onUfcOptionCueing2Change(char* newValue) {
  if (String(newValue).equals(" ")){
    matrix.clrPixel(OPT2Dot[0][0][0], OPT2Dot[0][0][1]);
  }else{
    matrix.setPixel(OPT2Dot[0][0][0], OPT2Dot[0][0][1]);
  }
  matrix.writeScreen();
}
DcsBios::StringBuffer<1> ufcOptionCueing2Buffer(0x742a, onUfcOptionCueing2Change);

void onUfcOptionCueing3Change(char* newValue) {
  if (String(newValue).equals(" ")){
    matrix.clrPixel(OPT3Dot[0][0][0], OPT3Dot[0][0][1]);
  }else{
    matrix.setPixel(OPT3Dot[0][0][0], OPT3Dot[0][0][1]);
  }
  matrix.writeScreen();
}
DcsBios::StringBuffer<1> ufcOptionCueing3Buffer(0x742c, onUfcOptionCueing3Change);

void onUfcOptionCueing4Change(char* newValue) {
  if (String(newValue).equals(" ")){
    matrix.clrPixel(OPT4Dot[0][0][0], OPT4Dot[0][0][1]);
  }else{
    matrix.setPixel(OPT4Dot[0][0][0], OPT4Dot[0][0][1]);
  }
  matrix.writeScreen();
}
DcsBios::StringBuffer<1> ufcOptionCueing4Buffer(0x742e, onUfcOptionCueing4Change);

void onUfcOptionCueing5Change(char* newValue) {
  if (String(newValue).equals(" ")){
    matrix.clrPixel(OPT5Dot[0][0][0], OPT5Dot[0][0][1]);
  }else{
    matrix.setPixel(OPT5Dot[0][0][0], OPT5Dot[0][0][1]);
  }
  matrix.writeScreen();
}
DcsBios::StringBuffer<1> ufcOptionCueing5Buffer(0x7430, onUfcOptionCueing5Change);

//COMM
void onUfcComm1DisplayChange(char* newValue) {
  String newString = String(newValue);
  newString.trim();
  if (newString.length() == 0){
    newString = " ";
  }
  int check = SearchIndex(newString);
  if (check == -1) return;
  DisplayChar(COMM1[0], Map16[check], 16);
  matrix.writeScreen();
}
DcsBios::StringBuffer<2> ufcComm1DisplayBuffer(0x7424, onUfcComm1DisplayChange);
void onUfcComm2DisplayChange(char* newValue) {
  String newString = String(newValue);
  newString.trim();
  if (newString.length() == 0){
    newString = " ";
  }
  int check = SearchIndex(newString);
  if (check == -1) return;
  DisplayChar(COMM2[0], Map16[check], 16);
  matrix.writeScreen();
}
DcsBios::StringBuffer<2> ufcComm2DisplayBuffer(0x7426, onUfcComm2DisplayChange);


//Brightness control via cockpit
void onInstPnlDimmerChange(unsigned int newValue) {
  analogWrite(BACKLIGHT, map(newValue, 0, 65535, 0, 255));
}
DcsBios::IntegerBuffer instPnlDimmerBuffer(0x7536, 0xffff, 0, onInstPnlDimmerChange);
//End DCS-BIOS


void loop() {
  DcsBios::loop();
  matrix.setCursor(0, 0);
  checkMatrix();
  checkSRs();

  joy.joyReport.buttons = buttonState;
  joy.sendReport();
  delay(1);
}

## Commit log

2021-05-09 WIP Kicad project
    [LowerBar.kicad_pcb, LowerBar.sch, UFC.kicad_pcb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]
2021-05-10 Rerouted scratchpad and added to main schematic
    Rerouted the scratchpad traces so that it has only 9 common pins, and two sets of anodes
    A-H and A-P for 16 segment, where each common goes to half a 16 seg digit, and 7 segments respectively, where each common goes to two 7 seg digits. I plan to tie the first set of A-H together with the second A-H, but the option to separately multiplex them is there.
    Also replaced the 1mm pitch headers with 2.54mm headers
    Added a symbol to the library and added it to the main UFC schematic.
    [displays.sch]
2021-05-10 Created scratchpad footprint
    Created a footprint for the scratchpad pins, and updated the layout
    [LowerBar.sch, UFC.kicad_pcb, UFC.sch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]
2021-05-12 Split up board, started routing traces
    Moved the LED drivers and the STM32 board off of the main board and onto a daughterboard to fit a reasonable space. Second board will go behind the first, connected with .1" headers.
    Additionally, traces on the bottom four (second LED driver) OPT displays are routed.
    Redid the OPT buttons to be included in the keypad matrix, to save pins.
    Removed the shift register pins and wired it all directly to the STM32, to save space
    [LowerBar.sch, UFC.kicad_pcb, UFC.sch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]
2021-05-13 Finished routing, updated comm channel displays
    Decided to use (and again modify) open hornet's com channel indicators. Finished routing traces and adding ground planes on the main board, though it may be a little sloppy. Began work on the back side board, which will have the LED drivers and STM32. Re added the shift register board for now for the sake of having more pins.
    [LowerBar.sch, UFC.kicad_pcb, UFC.sch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]
2021-05-14 Routed back side board
    Routed the LED drivers, pin headers, shift registers, etc. that are on the back side. ECAD is close to done, and I will start on the MCAD at this point.
    -Decided to avoid routing anodes and common cathodes to each of the comm channel displays, as that would probably have required at least an extra layer, instead I added a header to plug crimped wires directly into the front side.
    -Some of the headers are two single width pin headers put side by side, meaning their courtyards overlap. I may redo this to use one footprint for both in the future.
    -Still undecided on a couple part values
    [LowerBar.kicad_pcb, backside.kicad_pcb, backside.sch]
2021-05-14 Updated silkscreen, fixed minor issues
    Updated silkscreen to show pin designations, and fixed an issue with ground plane
    [LowerBar.kicad_pcb, LowerBar.sch, UFC.kicad_pcb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]
2021-05-14 Revert "Updated silkscreen, fixed minor issues"
    This reverts commit 7f968d800cd681b23a83898d0d52e0d98e75c2f4.
    [LowerBar.kicad_pcb, LowerBar.sch, UFC.kicad_pcb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]
2021-05-14 Updated silkscreen, fixed minor issues
    Updated silkscreen to include pin designations, and fixed minor issue with ground plane
    [LowerBar.sch, UFC.kicad_pcb, UFC.sch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]
2021-05-15 Removed comm displays from PCB
    Since they will be connected with wires anyways it didn't make sense to keep them on.
    [LowerBar.kicad_pcb, LowerBar.step, UFC.kicad_pcb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]
2021-05-15 Added folders via local upload
    Folders include updated panelized files, footprint library, gerbers, and display layers.
    [2xOPT Panelized template.kicad_pcb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]
2021-05-16 Added more space for connector on comm display
    [UFC-B_Cu.gbr, UFC-B_Mask.gbr, UFC-B_Paste.gbr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]
2021-05-18 Mostly finished UFC CAD
2021-05-30 Updated PCBs, cleaned up files
    No commit for a while; a lot has happened in the mean time. JLC refused my order for the display layers, so I settled for just the dot layer. The gerbers for the rest are deleted, but the kicad files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
    I also received the main PCBs from JLC, and edited a couple small details.
    [2xOPT Panelized-B_Cu.gbr, 2xOPT Panelized-B_Fab.gbr, 2xOPT Panelized-B_Mask.gbr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]
2021-05-30 Updated MCAD
    UFC CAD is finished, and now I just need to test print. Added STEP file for display layers 2-3, to be printed in resin or a <=0.2mm FDM nozzle.
    Laser cutting is an option but expensive
2021-06-08 STL Export
    [Back.stl, COMM retainer.stl, COMM.stl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]
2021-06-08 Started Firmware
    Firmware is just DCS-BIOS display code, for now. HID functions will be added soon.
    [Segment mapping.xlsx]
2021-06-10 Update MCAD screws
    Test printed top and face parts. Face part was missing screw holes, and counterbore for top part's M4 screws was not wide enough.
    [Face.stl, Top.stl]
2021-06-10 Face spacer
    Split face and spacing pegs to PCB for ease of printing
    [Face spacer.stl]
2021-06-11 Fixed design error
    Untested as of now.
    Removed direct connection from PWM out to LEDs, as the PWM pins on the bluepill can't provide enough current. Added P channel mosfet, and individual resistors per parallel LED. For now, the single resistor for all LEDs is still present, but bypassable via jumper, for the sake of backwards compatibility.
    [LowerBar-B_Cu.gbr, LowerBar-B_Mask.gbr, LowerBar-B_Paste.gbr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]
2021-06-11 Draft BOM
    Only has electronics components for now.
    [UFC BOM.xlsx]
2021-06-14 Updated channel knob dimensions
    Reduced the size of the hole for the channel selector from 9mm to 7mm, and added a hole for the indexer.
    [L side.stl, R side.stl]
2021-06-14 Major revision to backside PCB
    Re-arranged pin assignments on the bluepill; sacrificed 4 Analog inputs for 2 more digital interrupts, and 2 more SPI CS pins.
    Added two RJ12 connectors so that the board can be connected to other devices that use just shift registers, such as MFDs
    Replaced footprint for 3x shift register sub-assembly PCB with 2 DIP16 74hc165s, and pullups and bypass caps.
    Re-arranged and replaced 0.1" headers as appropriate.
    Removed R35 and its bypass jumper, connecting LEDPWM directly to the MOSFET drain.
    [backside-B_Cu.gbr, backside-B_Mask.gbr, backside-B_Paste.gbr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]
2021-06-21 Corrected extra shift register pins
    Replaced two latch pins with one latch and one data to one port, and made the other port daisy chained after the two shift registers on the board
    [backside-B_Cu.gbr, backside-B_Mask.gbr, backside-B_Paste.gbr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]
2021-07-18 Updated Keycaps
    Made the keycaps hollow to try to make the backlighting more visible. Updated the dimensions on M3 nut inserts; they were too small before
    [Key0.stl, Key1.stl, Key2.stl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]

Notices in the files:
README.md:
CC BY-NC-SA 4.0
